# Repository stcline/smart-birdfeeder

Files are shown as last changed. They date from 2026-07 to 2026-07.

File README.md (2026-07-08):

# Smart Birdfeeder

A Raspberry Pi–powered smart bird feeder with 4K video, AI-based species identification, Haikubox audio detection integration, NAS media storage, and a live web dashboard.

## Overview

This project combines a custom-designed outdoor enclosure (OnShape) with a Raspberry Pi 5 running motion detection and iNaturalist computer vision for visual species identification. Bird audio identifications from a [Haikubox](https://haikubox.com) device are pulled via the [BirdWeather API](https://app.birdweather.com) and merged into a unified SQLite logging database. All captures are stored locally on the Pi SD card until a NAS becomes available. A Flask-based dashboard (planned) will provide live video streaming, clip playback, species statistics, and links to [Cornell Lab of Ornithology](https://www.birds.cornell.edu) resources.

---

## Project Directories

| Directory | Description |
|---|---|
| [`/camera`](./camera) | Camera configuration, motion detection, capture scripts, and species ID |
| [`/haikubox`](./haikubox) | BirdWeather API poller — pulls Haikubox detections and writes to the logging database |
| [`/database`](./database) | SQLite schema and logging utilities |
| [`/dashboard`](./dashboard) | Flask web dashboard — live stream, clip gallery, species stats, Cornell Lab links |
| [`/scripts`](./scripts) | Setup, deployment, and maintenance scripts (NFS mount, service installs, etc.) |
| [`/config`](./config) | Environment variable templates and system configuration |
| [`/enclosure`](./enclosure) | OnShape design files, CAD exports, and enclosure documentation |
| [`/docs`](./docs) | Wiring diagrams, hardware specs, API references, and build notes |
| [`/archive`](./archive) | Retired files and replaced versions — kept for reference |

---

## Hardware

| Component | Model | Notes |
|---|---|---|
| Compute | Raspberry Pi 5 (4GB or 8GB) | Hostname: BirdHouse |
| Camera | Arducam 64MP OwlSight | CSI connection, manual focus LensPosition=12.0 |
| Cooling (SoC) | Official Raspberry Pi Active Cooler | Blower-style, mounts directly on Pi 5 |
| Cooling (enclosure) | Noctua NF-A4x10 5V PWM | GPIO-controlled exhaust fan |
| Audio Detection | Haikubox (existing hardware) | Reports to BirdWeather platform |
| Media Storage | NAS via NFS mount (pending build) | Currently storing to Pi SD card |
| Enclosure | Custom — OnShape design (PETG + TPU gasket, weatherproofed) | |
| Power | Official Raspberry Pi 27W USB-C PSU | Controlled by Shelly 1PM Plus smart switch |
| Smart Switch | Shelly 1PM Plus | Schedules power on/off at sunrise/sunset |

---

## Software Stack

| Layer | Tool |
|---|---|
| Motion detection | Custom picamera2 Python script with polygonal ROI |
| Species identification | [iNaturalist Computer Vision API](https://api.inaturalist.org/v1/docs/) |
| Audio detection | [Haikubox](https://haikubox.com) → [BirdWeather API](https://app.birdweather.com) |
| Data logging | SQLite |
| Dashboard | Python / Flask (planned) |
| Species reference | [Cornell Lab eBird API](https://ebird.org/api/keygen) |
| Media storage | NAS via NFS mount (Pi SD card currently) |
| System service | systemd — auto-starts on power-on |

---

## API Integrations

### iNaturalist Computer Vision
Used for visual species identification of captured images.

- Docs: [iNaturalist API v1](https://api.inaturalist.org/v1/docs/)
- Account: [inaturalist.org](https://www.inaturalist.org) (free)
- Token: [inaturalist.org/users/api_token](https://www.inaturalist.org/users/api_token) — expires every 24 hours
- Set `INAT_API_TOKEN` in `config/.env`

### BirdWeather (Haikubox)
Haikubox devices report detections to the BirdWeather platform. This project polls the BirdWeather API to retrieve detections for the registered station and writes them to the local database.

- API base: `https://app.birdweather.com/api/v1/`
- Key endpoint: `GET /stations/{station_id}/detections`
- Account: [app.birdweather.com](https://app.birdweather.com) (created with Haikubox setup)
- Set `BIRDWEATHER_STATION_ID` and `BIRDWEATHER_TOKEN` in `config/.env`
- See [`/haikubox`](./haikubox) for the polling script and setup instructions

### Cornell Lab eBird API
Used to enrich species records with taxonomy, range maps, and local sighting data.

- Docs: [eBird API 2.0](https://documenter.getpostman.com/view/664302/S1ENwy59)
- Account: [ebird.org](https://ebird.org) (free) — request API key at [ebird.org/api/keygen](https://ebird.org/api/keygen)
- Set `EBIRD_API_KEY` in `config/.env`
- Species pages: [AllAboutBirds](https://www.allaboutbirds.org/guide/) — linked per detection in the dashboard

---

## API Accounts Needed

| Service | URL | Purpose | Cost |
|---|---|---|---|
| iNaturalist | [inaturalist.org](https://www.inaturalist.org) | Visual species ID | Free |
| BirdWeather | [app.birdweather.com](https://app.birdweather.com) | Haikubox data (already set up with device) | Free |
| eBird / Cornell Lab | [ebird.org](https://ebird.org) | Species data, range maps, taxonomy | Free |

---

## Setup

> Full setup instructions are in [`/docs`](./docs). Quick start below.

```bash
# Clone the repo
git clone https://github.com/stcline/smart-birdfeeder.git
cd smart-birdfeeder

# Install Python dependencies (Raspberry Pi OS Bookworm)
sudo apt install python3-numpy python3-pil python3-requests python3-dotenv -y

# Copy and edit environment config
cp config/.env.example config/.env
nano config/.env   # add your API tokens

# Initialise the database
python3 -c "from database.db import init_db; init_db()"

# Install and enable the capture service
sudo cp camera/bird_capture.service /etc/systemd/system/
sudo systemctl daemon-reload
sudo systemctl enable bird_capture.service
sudo systemctl start bird_capture.service

# Monitor live output
journalctl -u bird_capture.service -f
```

---

## Bird Seed Selection

Choosing the right seed is important for attracting the widest variety of bird species and keeping the feeder healthy. The wrong seed attracts pests, molds quickly, and can discourage the birds you actually want.

### Recommended Seeds for Cypress, CA

| Seed | Birds Attracted | Notes |
|---|---|---|
| **Black oil sunflower seed** | Finches, chickadees, nuthatches, jays, sparrows, towhees | Best all-around choice — highest value seed you can offer. Thin shell makes it accessible to small-beaked birds. Aim for this to be 75%+ of what you offer |
| **Nyjer / thistle** | House finches, lesser goldfinches, pine siskins | Use a tube feeder with small ports. Very popular with SoCal finches year-round |
| **Safflower** | Cardinals, house finches, chickadees | Squirrels dislike it — good choice if squirrels are a problem |
| **Shelled peanuts (unsalted)** | Scrub jays, woodpeckers, nuthatches | High fat content, especially good in winter. Use a peanut feeder or platform |
| **Suet** | Woodpeckers, wrens, warblers | More relevant Oct–Mar in SoCal. Use a caged suet feeder to deter starlings |

### What to Avoid

- **Cheap mixed seed with millet or milo** — attracts house sparrows and pigeons while discouraging the species you want. If a bag is mostly small round seeds, put it back
- **Striped sunflower seed** — birds prefer black oil; striped is harder to open and less nutritious
- **Salted or flavored peanuts** — salt is harmful to birds

### Feeder Hygiene

- Clean the feeder every 1–2 weeks with a mild soap solution, rinse thoroughly, and let it dry completely before refilling
- Check after rain — wet seed molds quickly and can make birds sick
- Store seed in a sealed container in a cool dry location — seed does spoil

### Southern California Specific Notes

- **Lesser goldfinches** are extremely common in Cypress and will swarm a nyjer feeder
- **House finches** are year-round residents and love black oil sunflower
- **California scrub-jays** are regulars and prefer peanuts and suet
- **Anna's hummingbirds** are year-round in SoCal — a separate nectar feeder alongside the seed feeder is worth adding
- Avoid putting out food that attracts crows and pigeons in large numbers as they will dominate the feeder and deter smaller species

### Resources

- [AllAboutBirds — What do birds eat?](https://www.allaboutbirds.org/news/the-best-foods-for-your-bird-feeder/)
- [Cornell Lab — Seeds and Grains poster (PDF)](https://www.birds.cornell.edu/k12/wp-content/uploads/2023/02/SeedsandGrainsPoster.pdf)
- [UC ANR — Feed Wild Birds guide (PDF)](https://ucanr.edu/sites/default/files/2011-10/124156.pdf)
- [eBird — Recent sightings in Cypress, CA](https://ebird.org/hotspots?region=Cypress%2C+California%2C+US)

---

## Dashboard Features (Planned)

- Live 4K RTSP video stream (HLS in browser)
- Motion-triggered capture gallery with species labels
- Species detection log — visual (iNaturalist) and audio (Haikubox) merged
- Visit statistics by species, hour, and day
- Per-species links to [AllAboutBirds](https://www.allaboutbirds.org) and [eBird](https://ebird.org)
- Raspberry Pi system health (CPU temp, uptime)

---

## Archive

The [`/archive`](./archive) directory holds any files that have been superseded by updated versions. Files are moved here rather than deleted to preserve project history outside of git diffs.

---

## License

MIT

---

## References

- [iNaturalist Computer Vision API](https://api.inaturalist.org/v1/docs/)
- [BirdWeather API](https://app.birdweather.com)
- [Cornell Lab of Ornithology](https://www.birds.cornell.edu)
- [eBird API 2.0](https://documenter.getpostman.com/view/664302/S1ENwy59)
- [AllAboutBirds](https://www.allaboutbirds.org)
- [Haikubox](https://haikubox.com)
- [Arducam 64MP OwlSight](https://docs.arducam.com/Raspberry-Pi-Camera/Native-camera/64MP-OV64A40/)
- [Raspberry Pi Camera Documentation](https://www.raspberrypi.com/documentation/accessories/camera.html)
- [OnShape](https://www.onshape.com)
- [Shelly 1PM Plus](https://www.shelly.com/en-us/products/shop/shelly-plus-1-pm)

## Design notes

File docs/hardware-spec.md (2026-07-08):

# Smart Birdfeeder — Hardware Specification

This document captures all hardware decisions. Update when components change; move superseded versions to `/archive`.

---

## Compute

| Component | Model | Notes |
|---|---|---|
| Single-board computer | Raspberry Pi 5 (4GB or 8GB) | Hostname: BirdHouse; runs motion detection, iNaturalist ID, BirdWeather poller, and Flask dashboard |

---

## Power

| Component | Model | Notes |
|---|---|---|
| Power supply | Official Raspberry Pi 27W USB-C PSU | 5.1V / 5A; plugs into outdoor GFCI outlet via female spade terminals on plug prongs connected to hot/neutral wiring inside weatherproof junction box |
| Smart switch | Shelly 1PM Plus | Controls power to the outlet; scheduled on/off at sunrise/sunset via Shelly app — Pi powers down at night since no night vision |
| Cable entry | IP68 M20 cable gland | USB-C cable passes through gland on enclosure bottom or side face |

> **Note:** PoE was considered but not used — no Ethernet run is available at the installation location. Network connectivity is via the Pi 5's built-in Wi-Fi.

> **Note:** GPIO power path via IRM-30-5 AC-DC converter was evaluated but replaced with the official USB-C PSU for cleaner power delivery and proper Pi 5 voltage negotiation. IRM-30-5 archived.

---

## Cooling

Two-layer cooling strategy for outdoor enclosure use (Cypress, CA — high ambient summer temps).

| Component | Model | Purpose | Control |
|---|---|---|---|
| SoC cooler | [Official Raspberry Pi Active Cooler](https://www.raspberrypi.com/products/active-cooler/) | Cools Pi 5 SoC directly; mounts directly on Pi 5 | Pi firmware — automatic PWM |
| Enclosure exhaust fan | [Noctua NF-A4x10 5V PWM](https://www.amazon.com/Noctua-NF-A4x10-5V-PWM-Premium/dp/B07DXS86G7/) (ASIN: B07DXS86G7) | Exhausts hot air from electronics compartment through louvered vent | GPIO PWM script — temperature-triggered (~65°C on, 100% at 75°C+) |

### Fan Wiring (GPIO Header)

| Fan Wire | Color | GPIO Pin | Function |
|---|---|---|---|
| Ground | Black | Pin 6 | GND |
| Power | Yellow | Pin 4 | 5V |
| PWM | Blue | Pin 33 (GPIO13) | Hardware PWM speed control |
| Tach | Green | Pin 35 (GPIO19) | Optional — RPM monitoring |

A BSS138 logic level shifter (3.3V → 5V) is recommended between GPIO PWM pin and fan PWM wire for full speed ramping. Alternatively wire for on/off control only.

### Enclosure Cooling Design Notes
- Electronics compartment physically separated from birdseed compartment by internal partition
- Noctua fan mounts in 40mm cutout in electronics compartment wall (4× M3 holes on 32mm bolt circle)
- Fan exhausts outward; intake is filtered vent on opposite face (bottom preferred for rain protection)
- Vents covered with 0.45µm hydrophobic PTFE membrane held by printed PETG retaining rings
- Light-colored exterior to minimize solar gain
- Pi SoC temperature monitored via `vcgencmd measure_temp` and surfaced in dashboard

### Stack Height
Pi 5 + Official Active Cooler stacked height should be confirmed from Raspberry Pi documentation before finalizing electronics compartment height in OnShape.

---

## Camera

| Status | Model | Focal Length | FoV (H) | Resolution | Notes |
|---|---|---|---|---|---|
| **Selected** | **Arducam 64MP OwlSight** | **6.65mm** | **68°** | **64MP** | Manual focus; LensPosition=12.0 for feeder distance ~10–13cm; CSI connection |
| Evaluated | Pi Camera Module 3 (standard) | 4.74mm | 66° | 12MP (Sony IMX708) | Good low-light; lower resolution |
| Evaluated | Pi Camera V2, Pi AI Camera | Similar FoV | ~66° | 12MP | Not selected |
| Avoid | Pi Camera Module 3 Wide | 2.75mm | 102° | 12MP | Too wide for close feeder distance |

**Capture resolution in use:** 4056×3040 (balanced quality vs. file size)
**dtoverlay:** `dtoverlay=ov64a40,link-frequency=360000000` with `camera_auto_detect=0`

---

## Enclosure

| Item | Detail |
|---|---|
| CAD software | [OnShape](https://www.onshape.com) (cloud-based, free for public projects) |
| Body material | PETG — UV resistant, ~80°C heat deflection, easy to print |
| Gasket material | Shore 95A TPU — compresses to seal against PETG mating surface |
| Fasteners | Stainless M3/M4 screws throughout — corrosion resistant |
| Lid seal | Compression fit with captured TPU gasket in routed groove; 4–6 stainless screws around perimeter |
| Cable entry | IP68 M20 cable gland on bottom or side face — never top |
| Vent membranes | 0.45µm hydrophobic PTFE membrane with PETG snap-fit retaining rings |
| Fan cutout | 40mm circular, 32mm bolt circle for M3 mounting screws |

Design files stored in [`/enclosure`](../enclosure).

---

## Bird Audio Detection

| Component | Model | Notes |
|---|---|---|
| Audio detector | [Haikubox](https://haikubox.com) | Existing hardware — kept in place; reports to BirdWeather platform |
| API integration | [BirdWeather API](https://app.birdweather.com/api/v1/) | Polled by Python script in `/haikubox`; detections merged into local SQLite database |

No additional audio hardware is planned. The Haikubox handles all audio-based species identification.

---

## Media Storage

| Component | Notes |
|---|---|
| Current | Pi SD card — `/home/steve/birdfeeder/captures/` |
| Planned | NAS via NFS mount — separate NAS build in progress |
| Protocol | NFSv3 or NFSv4 |
| NAS directory structure | `/birdfeeder/clips/` and `/birdfeeder/snapshots/` |
| Retention policy | Clips: 7 days auto-delete; snapshots: 30 days; `/saved/`: never deleted |
| Transition | Update `SAVE_DIR` in `config/.env` and `bird_capture.py` when NAS is ready |

---

## Optional Upgrades

| Component | Purpose | Notes |
|---|---|---|
| Google Coral USB Accelerator | Offloads object detection from CPU | ~$60–80; USB 3.0 plug-and-play; add if CPU temps become problematic |

---

## Shopping List

| Item | Source | Approx. Cost | Status |
|---|---|---|---|
| Raspberry Pi 5 (4GB or 8GB) | raspberrypi.com / Amazon | $60–80 | Purchased |
| Official Pi 5 Active Cooler | raspberrypi.com / Amazon | $5 | Purchased |
| Noctua NF-A4x10 5V PWM (ASIN: B07DXS86G7) | [Amazon](https://www.amazon.com/dp/B07DXS86G7) | $16 | Purchased |
| Arducam 64MP OwlSight | Amazon | $50 | Purchased |
| Official Raspberry Pi 27W USB-C PSU | raspberrypi.com / Amazon | $12 | Purchased |
| Shelly 1PM Plus | shelly.com / Amazon | $20 | Purchased |
| IP68 M20 cable gland | Amazon | $2 | Purchased |
| 0.45µm PTFE membrane (hydrophobic) | Amazon | $8–12 | Pending |
| BSS138 logic level shifter module | Amazon | $2 | Pending |
| Stainless M3/M4 hardware | Amazon / hardware store | $5 | Pending |
| PETG filament (enclosure body) | Amazon / Prusament | $20–25 | Pending |
| TPU filament Shore 95A (gasket) | Amazon | $20–25 | Pending |

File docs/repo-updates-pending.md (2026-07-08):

# Pending Repository Updates

Items discussed in conversation that need to be applied to the repo.
Work through these in a dedicated session.

---

## hardware-spec.md

- [ ] Add enclosure materials section — PETG body, Shore 95A TPU gasket, design notes
      (discussed: compression lid, stainless hardware, drip edge, gland placement,
      wall thickness 3-4 perimeters, 40%+ infill, louvered vent as separate insert)

- [ ] Update power section — replace IRM-30-5 GPIO path with USB-C supply via
      female spade terminals on plug prongs, connected to hot/neutral in junction box,
      USB-C cable through IP68 gland into enclosure to Pi 5 USB-C port

- [ ] Add wiring diagram document to /docs covering full power chain:
      Outlet → GFCI → junction box → spade terminals on USB-C supply plug →
      USB-C cable → IP68 gland → Pi 5 USB-C port

- [ ] Add network section — Pi 5 built-in Wi-Fi (no Ethernet run available);
      note on metal enclosure attenuation risk; static IP / DHCP reservation recommended

---

## README.md

- [ ] Update shopping list to reflect USB-C power supply instead of IRM + GPIO path
- [ ] Add enclosure section linking to /enclosure directory

---

## New Files Needed

- [ ] /docs/wiring-diagram.md — full power chain documentation
- [ ] /docs/enclosure-design-notes.md — PETG/TPU material choices, CAD design guidelines,
      thermal separation, fan cutout dimensions (40mm, 32mm bolt circle),
      gland placement rules, compression lid spec
- [ ] /scripts/auto_delete.py — cron-based retention policy script:
      /clips/ 7 days, /snapshots/ 30 days, /saved/ never touched
- [ ] /scripts/mount_nas.sh — NFS mount script (pending NAS build)
- [ ] /config/.env.example — environment variable template

---

## scripts/refresh_inat_token.py

- [ ] iNaturalist OAuth app registration requires account to be 2+ months old
      AND 10 improving identifications made for other users in the last month.
      Until qualified: manually refresh token daily at
      https://www.inaturalist.org/users/api_token and paste into config/.env.
      No service restart needed after updating the token.
      Once qualified, register app at https://www.inaturalist.org/oauth/applications/new
      and add INAT_USERNAME, INAT_PASSWORD, INAT_APP_ID, INAT_APP_SECRET to config/.env,
      then install the cron job (see script header for instructions).

---

## camera/identify.py + database/db.py

- [ ] Only generate Cornell Lab links when iNaturalist result is a bird
      (check `iconic_taxon_name == "Aves"` in API response before building URLs)
- [ ] Fix eBird URL format — eBird uses 6-letter species codes (e.g. `houfin`)
      not common name slugs. Look up correct code via eBird API or iNaturalist
      taxon data
- [ ] Update `min_confidence` threshold in identify.py to use a meaningful
      cutoff on the raw score (suggest 50) rather than 0.10 which is ineffective
- [ ] Add Samba file share setup to /docs or /scripts for PC access to captures
      and database

---

## camera/bird_capture.py

- [ ] Update SAVE_DIR to NAS NFS mount path once NAS is built
      (current: /home/steve/birdfeeder/captures)
- [ ] Update script path in bird_capture.service to match final deployment location

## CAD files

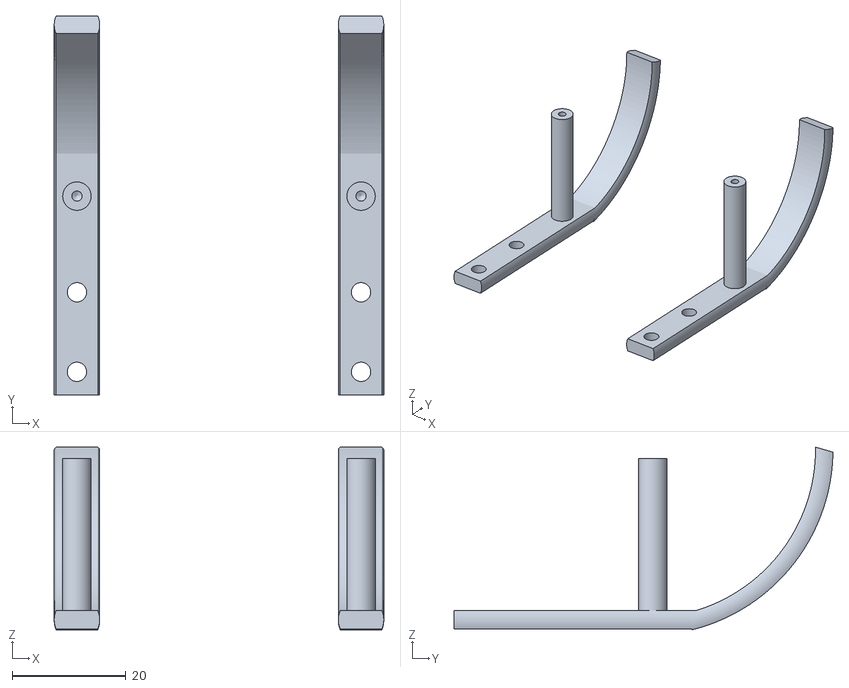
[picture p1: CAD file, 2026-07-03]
enclosure/Porch_base_FINAL.stl
58.0 x 66.7 x 32.2

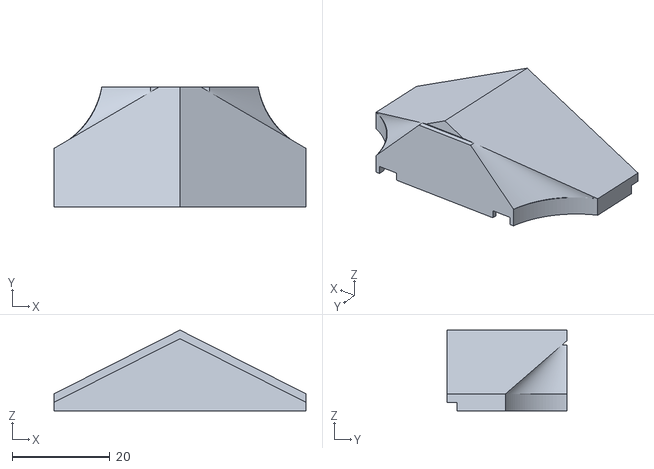
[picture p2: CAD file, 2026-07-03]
enclosure/Camera_roof.stl
51.5 x 24.6 x 16.5

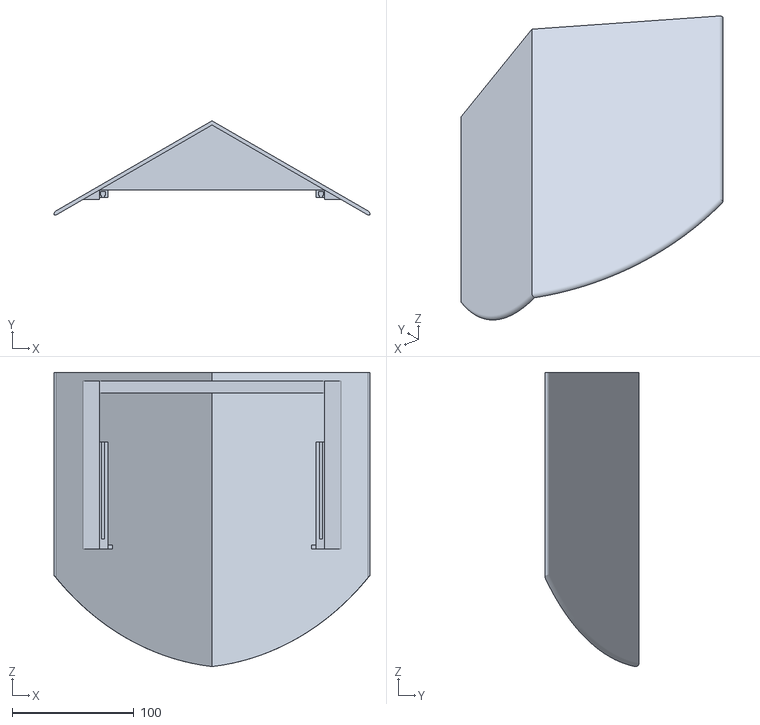
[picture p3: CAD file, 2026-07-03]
enclosure/Birdhouse_Roof_FINAL.stl
259.8 x 77.6 x 241.8

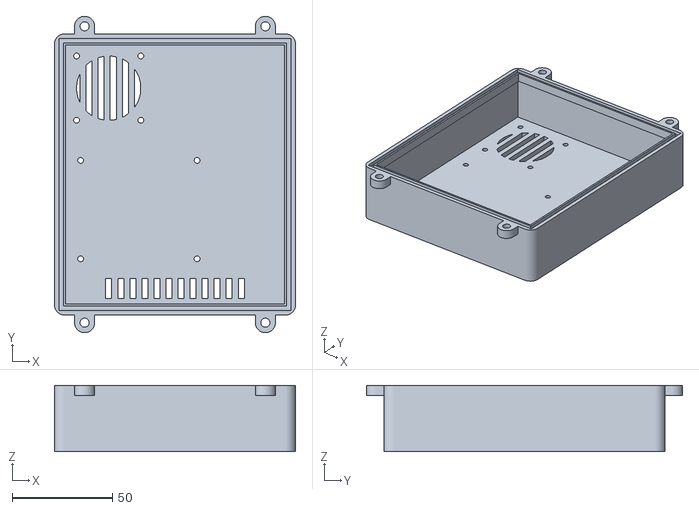
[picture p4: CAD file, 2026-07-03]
enclosure/Electronics_housing_FINAL.stl
120.0 x 157.5 x 33.0

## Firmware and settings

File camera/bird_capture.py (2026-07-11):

"""
bird_capture.py
---------------
Monitors the birdfeeder perch for motion and captures a still image
when a bird is detected. Images are saved locally to the Pi SD card.

Later versions will write to NAS via NFS mount instead.

Hardware: Arducam 64MP OwlSight on Raspberry Pi 5 (Bookworm)
Author:   Smart Birdfeeder Project
"""

import os
import sys
import time
import logging
import numpy as np
from PIL import Image, ImageDraw
from datetime import datetime
from dotenv import load_dotenv

# Load environment variables from config/.env
# Use absolute path so it works whether run directly or via systemd
_ENV_PATH = os.path.join(os.path.dirname(os.path.abspath(__file__)), "..", "config", ".env")
load_dotenv(_ENV_PATH)

from picamera2 import Picamera2, Preview
from libcamera import controls

# Add project root to path for database module
sys.path.insert(0, os.path.join(os.path.dirname(__file__), ".."))
from camera.identify import identify_bird
from camera.notify import send_bird_alert
from database.db import init_db, log_sighting

# ─── SUPPRESS LIBCAMERA NOISE ────────────────────────────────────────────────
os.environ["LIBCAMERA_LOG_LEVELS"] = "ERROR"

# ─── CONFIGURATION ────────────────────────────────────────────────────────────
# Storage — local SD card (swap path to NAS mount later)
SAVE_DIR = "/home/steve/birdfeeder/captures"

# Camera — set LensPosition for your feeder distance
# 12.0 = sharp at ~10-13cm. Adjust based on your calibration results.
LENS_POSITION = 12.0

# Image resolution — balance between detail and file size
# Full 64MP: (9152, 6944) | High quality: (4056, 3040) | Balanced: (2028, 1520)
CAPTURE_RESOLUTION = (4056, 3040)

# Motion detection sensitivity
# Lower = more sensitive (more false triggers)
# Higher = less sensitive (may miss small birds)
MOTION_THRESHOLD = 25       # pixel difference to count as changed
MOTION_MIN_PIXELS = 3000    # raised — filters empty-frame triggers; bird landing ~9500px

# Perch ROI — polygon defining the feeder perch area in lores (640x480) coords
# Only motion inside this polygon triggers a capture
# Coordinates defined from reference frame (before 180° rotation applied to captures)
PERCH_ROI = [
    (0,   0),
    (640, 0),
    (640, 74),
    (454, 86),
    (205, 89),
    (0,   80),
]


# Cooldown between captures (seconds) — prevents burst captures of same bird
CAPTURE_COOLDOWN = 5

# Frames to average for background model
BACKGROUND_FRAMES = 10

# Logging
LOG_FILE = "/home/steve/birdfeeder/bird_capture.log"

# ─── SETUP LOGGING ────────────────────────────────────────────────────────────
os.makedirs(SAVE_DIR, exist_ok=True)
os.makedirs(os.path.dirname(LOG_FILE), exist_ok=True)

logging.basicConfig(
    level=logging.INFO,
    format="%(asctime)s  %(levelname)s  %(message)s",
    handlers=[
        logging.FileHandler(LOG_FILE),
        logging.StreamHandler()
    ]
)
log = logging.getLogger(__name__)


# ─── CAMERA SETUP ─────────────────────────────────────────────────────────────
def init_camera():
    """Initialise Arducam 64MP with manual focus and still capture config."""
    cam = Picamera2()

    # Low-resolution stream for motion detection (fast, low CPU)
    # High-resolution stream for actual captures
    config = cam.create_video_configuration(
        main={"size": CAPTURE_RESOLUTION, "format": "RGB888"},
        lores={"size": (640, 480),        "format": "YUV420"},
        display=None
    )
    cam.configure(config)
    cam.start_preview(Preview.NULL)
    cam.start()

    # Set manual focus to calibrated feeder distance
    cam.set_controls({
        "AfMode": controls.AfModeEnum.Manual,
        "LensPosition": LENS_POSITION
    })

    time.sleep(2)  # Let camera and lens settle
    log.info(f"Camera initialised — LensPosition={LENS_POSITION}, "
             f"capture resolution={CAPTURE_RESOLUTION}")
    return cam


# ─── ROI MASK ────────────────────────────────────────────────────────────────
def build_roi_mask(polygon, frame_size=(480, 640)):
    """
    Build a boolean numpy mask from a polygon defined in (x, y) coords.
    True inside the polygon (the perch zone), False outside.
    """
    img = Image.new("L", (frame_size[1], frame_size[0]), 0)
    ImageDraw.Draw(img).polygon(polygon, fill=255)
    mask = np.array(img, dtype=bool)
    log.info(f"ROI mask built — {mask.sum()} pixels in perch zone")
    return mask


# ─── BACKGROUND MODEL ─────────────────────────────────────────────────────────
def build_background(cam, n_frames=BACKGROUND_FRAMES):
    """
    Capture several lores frames and average them to build
    a baseline background image for motion detection.
    """
    log.info(f"Building background model from {n_frames} frames...")
    frames = []
    for _ in range(n_frames):
        frame = cam.capture_array("lores")
        # YUV420 — take Y (luma) channel only, reshape to 2D
        y_channel = frame[:480, :640].astype(np.float32)
        frames.append(y_channel)
        time.sleep(0.1)

    background = np.mean(frames, axis=0)
    log.info("Background model ready.")
    return background


# ─── MOTION DETECTION ─────────────────────────────────────────────────────────
def detect_motion(cam, background, roi_mask):
    """
    Compare current lores frame against background model.
    Only pixels inside the perch ROI polygon are evaluated.
    Returns True if significant motion is detected.
    """
    frame = cam.capture_array("lores")
    y_channel = frame[:480, :640].astype(np.float32)

    # Absolute difference from background
    diff = np.abs(y_channel - background)

    # Only count changed pixels inside the perch polygon
    changed_pixels = np.sum((diff > MOTION_THRESHOLD) & roi_mask)

    return changed_pixels > MOTION_MIN_PIXELS, changed_pixels


# ─── CAPTURE ──────────────────────────────────────────────────────────────────
def capture_bird(cam):
    """Capture a full-resolution still and save to SAVE_DIR."""
    timestamp = datetime.now().strftime("%Y%m%d-%H%M%S")
    filename = f"bird_{timestamp}.jpg"
    filepath = os.path.join(SAVE_DIR, filename)

    # Rotate 180° — camera is mounted inverted in enclosure
    request = cam.capture_request()
    image = request.make_image("main")
    request.release()
    image = image.rotate(180)
    image.save(filepath)
    metadata = cam.capture_metadata()

    log.info(f"Captured: {filename} | "
             f"Exposure={metadata.get('ExposureTime','?')}µs | "
             f"Gain={metadata.get('AnalogueGain','?'):.2f} | "
             f"LensPos={metadata.get('LensPosition','?')}")

    # ── Species identification ──────────────────────────────────────────
    id_result = identify_bird(filepath)

    # ── Push notification ─────────────────────────────────────────────
    if id_result:
        send_bird_alert(
            common_name=id_result["common_name"],
            scientific_name=id_result["scientific_name"],
            confidence=id_result["confidence"],
            image_path=filepath,
        )

    # ── Log to database ────────────────────────────────────────────────
    log_sighting(
        timestamp=datetime.now().isoformat(),
        image_path=filepath,
        common_name=id_result["common_name"] if id_result else None,
        scientific_name=id_result["scientific_name"] if id_result else None,
        confidence=id_result["confidence"] if id_result else None,
        taxon_id=id_result["taxon_id"] if id_result else None,
        lens_position=metadata.get("LensPosition"),
        exposure_us=metadata.get("ExposureTime"),
        analogue_gain=metadata.get("AnalogueGain"),
        source="camera"
    )

    return filepath


# ─── MAIN LOOP ────────────────────────────────────────────────────────────────
def main():
    log.info("=== Smart Birdfeeder Capture Starting ===")
    log.info(f"Saving images to: {SAVE_DIR}")

    # Initialise database
    init_db()

    cam = init_camera()
    roi_mask = build_roi_mask(PERCH_ROI)
    background = build_background(cam)

    last_capture_time = 0

    log.info("Monitoring for birds... (Ctrl+C to stop)")

    try:
        while True:
            motion_detected, changed_pixels = detect_motion(cam, background, roi_mask)

            if motion_detected:
                now = time.time()
                if now - last_capture_time >= CAPTURE_COOLDOWN:
                    log.info(f"Motion detected — {changed_pixels} pixels changed")
                    capture_bird(cam)
                    last_capture_time = now

                    # Rebuild background after capture to account for
                    # perch state change (bird now present)
                    time.sleep(1)
                    background = build_background(cam)  # roi_mask unchanged
                else:
                    remaining = CAPTURE_COOLDOWN - (now - last_capture_time)
                    log.debug(f"Motion detected but in cooldown "
                              f"({remaining:.1f}s remaining)")

            time.sleep(0.2)  # ~5 fps motion check rate

    except KeyboardInterrupt:
        log.info("Stopped by user.")
    finally:
        cam.stop()
        log.info("Camera released. Exiting.")


if __name__ == "__main__":
    main()

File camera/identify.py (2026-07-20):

"""
identify.py
-----------
Bird species identification via the iNaturalist Computer Vision API.
Called immediately after each capture in bird_capture.py.

API docs: https://api.inaturalist.org/v1/docs/
Auth:     JWT token from https://www.inaturalist.org/users/api_token
          Token expires every 24 hours — script auto-refreshes via env var.
"""

import os
import logging
import requests
from dotenv import load_dotenv

log = logging.getLogger(__name__)

# Resolve .env path relative to this file — works regardless of working directory
_ENV_PATH = os.path.join(os.path.dirname(os.path.abspath(__file__)), "..", "config", ".env")

INAT_API_BASE = "https://api.inaturalist.org/v1"

# Location hint — improves ID accuracy by narrowing to local species
# Cypress, CA coordinates
LOCATION_LAT = 33.8169
LOCATION_LNG = -118.0375

# Minimum vision_score (0.0–1.0) to accept a result.
# 0.50 = iNaturalist needs to be at least 50% confident it's this species.
# vision_score is the per-image ML probability; combined_score is a raw
# ranking score that can exceed 1.0 and should NOT be used as a threshold.
MIN_CONFIDENCE = 0.50


def get_token() -> str:
    """
    Read iNaturalist JWT token from .env file directly.
    Reloads on every call so token updates without restarting the service.
    Set INAT_API_TOKEN in your config/.env file.
    """
    load_dotenv(_ENV_PATH, override=True)
    token = os.environ.get("INAT_API_TOKEN", "")
    if not token:
        raise EnvironmentError(
            "INAT_API_TOKEN not set. Add it to config/.env"
        )
    return token


def identify_bird(image_path: str, min_confidence: float = MIN_CONFIDENCE) -> dict | None:
    """
    Submit a captured image to the iNaturalist Computer Vision API.
    Only returns a result if:
      1. The top result is classified as a bird (iconic_taxon_name == "Aves")
      2. The vision_score (0.0–1.0) is at or above min_confidence

    Args:
        image_path:      Absolute path to the captured JPEG
        min_confidence:  Minimum vision_score to accept (0.0–1.0)
                         Default 0.50 — require 50% confidence

    Returns:
        {
            "common_name":     str,
            "scientific_name": str,
            "confidence":      float,   # vision_score, 0.0–1.0
            "taxon_id":        int,
        }
        or None if no bird result above min_confidence
    """
    try:
        token = get_token()

        with open(image_path, "rb") as img_file:
            response = requests.post(
                f"{INAT_API_BASE}/computervision/score_image",
                headers={"Authorization": f"Bearer {token}"},
                files={"image": img_file},
                data={
                    "lat": LOCATION_LAT,
                    "lng": LOCATION_LNG,
                },
                timeout=30
            )

        if response.status_code == 401:
            log.error("iNaturalist token rejected (401) — check INAT_API_TOKEN in config/.env")
            return None

        if response.status_code != 200:
            log.error(f"iNaturalist API error {response.status_code}: {response.text[:200]}")
            return None

        results = response.json().get("results", [])

        if not results:
            log.info("iNaturalist returned no results for this image")
            return None

        top = results[0]
        taxon = top.get("taxon", {})

        # ── Bird-only filter ────────────────────────────────────────────────
        # iconic_taxon_name == "Aves" means it's a bird.
        # Without this, insects, plants, fungi, etc. can sneak through.
        iconic = taxon.get("iconic_taxon_name")
        if iconic != "Aves":
            log.info(
                f"Non-bird result filtered out: {taxon.get('name', 'Unknown')} "
                f"(iconic_taxon_name={iconic!r})"
            )
            return None

        # ── Use vision_score (0.0–1.0), not combined_score ─────────────────
        # combined_score is a raw ranking number that can exceed 1.0 and
        # is NOT suitable as a confidence percentage threshold.
        confidence = top.get("vision_score", 0)

        common_name = taxon.get("preferred_common_name") or taxon.get("name", "Unknown")
        scientific_name = taxon.get("name", "Unknown")
        taxon_id = taxon.get("id")

        if confidence < min_confidence:
            log.info(
                f"Low confidence bird: {common_name} (score={confidence:.2f}) "
                f"— below threshold {min_confidence:.2f}, skipping"
            )
            return None

        result = {
            "common_name":     common_name,
            "scientific_name": scientific_name,
            "confidence":      confidence,
            "taxon_id":        taxon_id,
        }

        log.info(
            f"Bird identified: {common_name} ({scientific_name}) "
            f"— score {confidence:.2f}"
        )

        # Log runner-up for reference (if also a bird)
        if len(results) > 1:
            runner = results[1]
            runner_taxon = runner.get("taxon", {})
            runner_name = runner_taxon.get("preferred_common_name", runner_taxon.get("name", "?"))
            runner_conf = runner.get("vision_score", 0)
            runner_iconic = runner_taxon.get("iconic_taxon_name")
            if runner_iconic == "Aves":
                log.info(f"  Runner-up: {runner_name} (score={runner_conf:.2f})")

        return result

    except requests.exceptions.Timeout:
        log.error("iNaturalist API timed out after 30s")
        return None
    except requests.exceptions.ConnectionError:
        log.error("iNaturalist API unreachable — check Wi-Fi connection")
        return None
    except Exception as e:
        log.error(f"Unexpected error during bird ID: {e}")
        return None

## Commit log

2026-06-14 Update hardware spec: replace PoE with AC-DC converter power system
2026-07-02 Rotate capture image 180 degrees — camera mounted inverted in enclosure
    [bird_capture.py]
2026-07-02 Add polygonal perch ROI for motion detection — ignores background tree movement
2026-07-07 Fix env path resolution for systemd and None confidence formatting bug
    [bird_capture.py]
2026-07-07 Fix token loading in identify.py — reload .env directly on each call
    [identify.py]
2026-07-07 Fix species registry query — use taxon_id not id as lookup column
2026-07-08 Update README and hardware spec: OnShape, USB-C power, Shelly, bird seed section, API accounts
2026-07-08 fix(identify): bird-only filter, use vision_score, raise min confidence to 50%
    - Add iconic_taxon_name == 'Aves' check — filters out insects, plants, fungi
    - Switch from combined_score to vision_score (0.0-1.0) — combined_score is a
    raw ranking number that can exceed 1.0 and is not a confidence percentage
    - Raise MIN_CONFIDENCE from 0.10 to 0.50 (50%)
    - Only log bird runner-up species in runner-up line
    - Add detailed comments explaining score field meanings
    [identify.py]
2026-07-11 tune(capture): raise MOTION_MIN_PIXELS from 500 to 3000
    Empty frames were triggering API calls — iNaturalist returns low-confidence
    junk IDs on featureless images. Bird landing = ~9500px, false triggers = ~500px.
    3000px threshold skips API call for small motion events.
    [bird_capture.py]
2026-07-11 feat(notify): add Pushover push notifications for bird sightings
    - Add camera/notify.py — Pushover helper with image attachment support
    - Wire send_bird_alert() into bird_capture.py after successful ID
    - Only fires when PUSHOVER_USER_KEY and PUSHOVER_APP_TOKEN are set in .env
    - Silently skips if credentials missing — service keeps running
    - Add Pushover keys to .env.example with setup instructions
    - Image attached to notification if under 2.5 MB Pushover limit
    [bird_capture.py, notify.py]
2026-07-20 fix: display raw iNaturalist score instead of percentage
    vision_score is a raw float (e.g. 10.5), not a 0.0-1.0 probability.
    Formatting with :.1% was multiplying by 100 causing 1000%+ displays.
    Now shown as a plain 2-decimal float in logs, DB, and Pushover alerts.
    [identify.py, notify.py]
